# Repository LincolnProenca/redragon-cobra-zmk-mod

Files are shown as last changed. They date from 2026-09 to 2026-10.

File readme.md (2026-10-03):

# Custom ZMK Wireless Mouse: Redragon Cobra Mod 🖱️🐍

> **Hardware & Firmware Engineering Portfolio**

<p align="center">
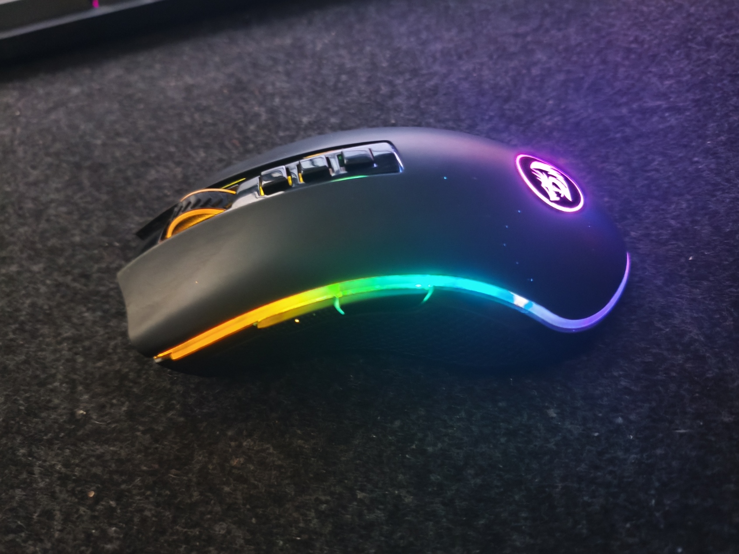
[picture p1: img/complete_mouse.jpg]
Finished Mouse with RGB
  
</p>

A comprehensive hardware and firmware project focused on creating a custom wireless mouse, built upon the Zephyr/ZMK ecosystem. A core idea behind this project was to create a versatile tool that seamlessly transitions between my work and home environments.

The project involved **designing a custom PCB**, specifically tailored to fit perfectly within the ergonomic shell of a **Redragon Cobra**. A key goal was to reuse as many components from the original mouse as possible—such as the switches and the wheel mechanism—transforming a traditional wired mouse into a premium, high-performance wireless tool.

Focused on energy efficiency, multiple productivity layers (Office/Gaming), and RGB Underglow lighting, the development overcame several electrical and logical challenges, especially in integrating high-consumption components (LEDs) with a _low-power_ sensor architecture.

## 📸 Project Gallery (Build Log)

<div align="center">
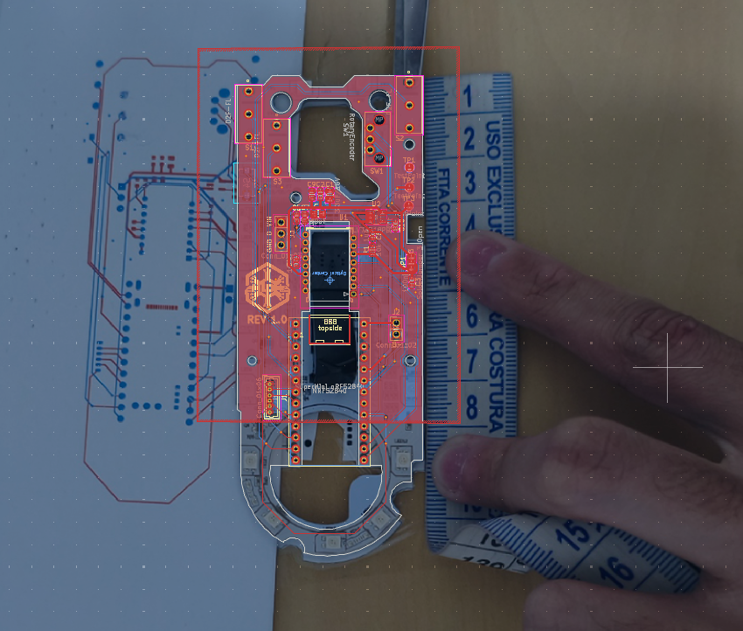
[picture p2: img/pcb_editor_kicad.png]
KiCad PCB Editor
  
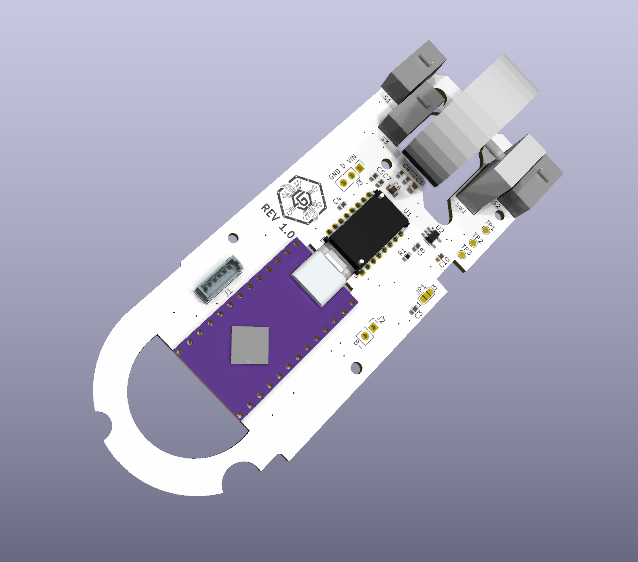
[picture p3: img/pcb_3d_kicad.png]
PCB 3D Render in KiCad
  
</div>
<br/>
<div align="center">
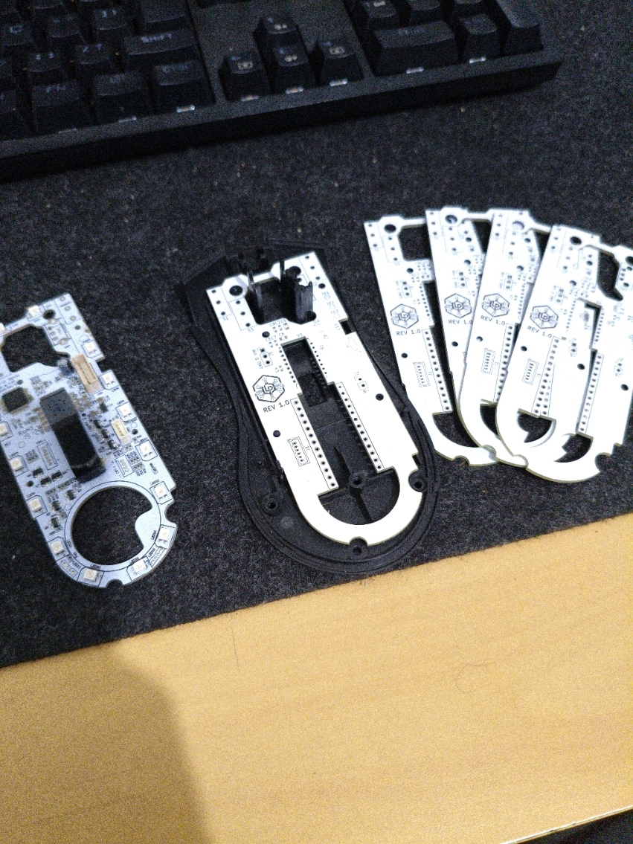
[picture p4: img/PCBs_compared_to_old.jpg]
Comparison with the Old PCB
  
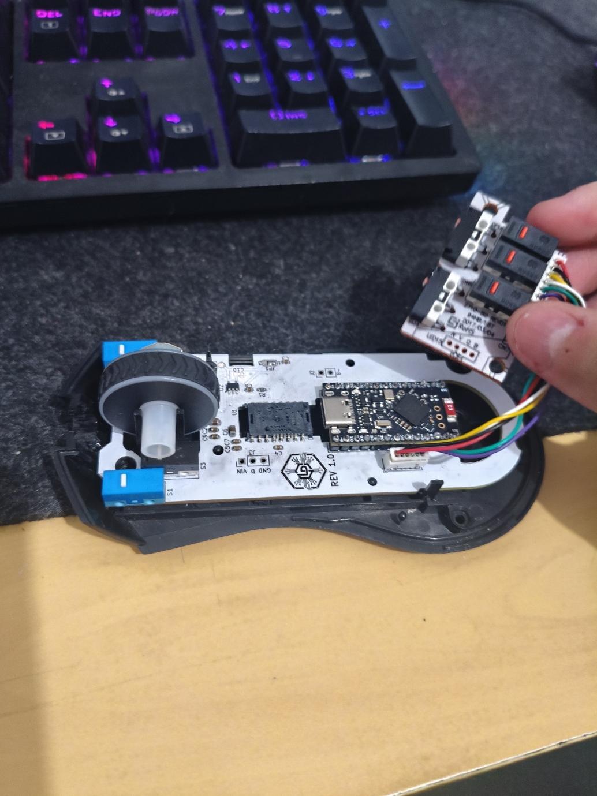
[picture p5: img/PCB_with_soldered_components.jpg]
Soldered PCB
  
</div>

## 🛠️ Hardware Specifications & Custom PCB

The hardware architecture was custom-developed to reuse the Redragon Cobra shell and its main functional components (like the original clicks and side switches). The integration includes:

- **Microcontroller:** SuperMini nRF52 (nice!nano alternative based on the nRF52840)
- **Optical Sensor:** PixArt PMW3610 (Since the original was a wired sensor, it was replaced with this Low-Power architecture ideal for wireless)
- **Scroll / Wheel:** TTC Gold 13mm Rotary Encoder (The original encoder was damaged and an exact replacement wasn't available, so it was swapped for this equivalent TTC Gold)
- **Lighting:** WS2812 LED Strip (9 LEDs for underglow)
- **Battery:** 1200mAh 3.7V LiPo (Model 503048, 5x30x48mm)
- **LED Power Control:** Two-stage power-gating circuit (level shifter): an **A19T P-channel MOSFET**(salvaged from a damaged SuperMini) switches the raw battery line (B+) to the LED strip VCC, and its gate is driven by an **SS8050 NPN transistor** (label Y1, salvaged from the original Redragon Cobra PCB) acting as a level shifter. The NPN base is driven by the MCU's `EXT_POWER` pin (GPIO 1.11) through a ~1.4k base resistor (also salvaged from the damaged SuperMini). This guarantees full enhancement and full cut-off of the MOSFET across the entire battery range (3.0V–4.2V).

## ✨ Features and Functionalities

The firmware was designed to act as a hybrid device (Mouse + Keyboard), allowing the execution of complex macros and direct shortcuts on the board.

### Layer System

- **Gaming Layer (Default):** Standard mouse commands (LCLK, RCLK, MCLK, MB4, MB5) with high-sensitivity scroll.
- **Office Layer:** Transforms the mouse into a productivity tool focused on **Simulink** environments. Features built-in macros (`Ctrl + .`, `C`, `E`, `N`, `T`, `E`, `R`) injected in 30ms for quick alignments, compiling, and block organization.
- **Utility Layer (Bluetooth Modifier):** Holding the "Top 3" button transforms the main clicks into a Bluetooth remote control (Force Slot 0, Force Slot 1, Format Memory).

### Physical Combos

- **TOP_1 + TOP_2:** Clean Soft Off (cuts `EXT_POWER` first, then enters deep sleep).
- **TOP_1 + TOP_3:** Toggle RGB On/Off.
- **TOP_2 + TOP_3:** Next RGB effect.
- **SIDE_1 + SIDE_2:** System Reset (Hardware sys_reset).
- **Bottom Button:** Directly triggers System Reset.

> Combos were deliberately moved off the main click buttons (LMB/RMB/MMB): any key position participating in a combo is held for up to `timeout-ms` on every press, which added perceptible latency to middle-click drags.

## ⚡ Engineering Notes & Hardware Solutions

During development, several electrical integration and mechanical design bottlenecks were resolved. If you intend to replicate this project, pay attention to the following design decisions and topology rules:

### 1. PCB Modeling and Component Alignment

Without schematics for the original Redragon Cobra PCB, the new board had to be modeled from scratch. The PCB outline and component placements were reverse-engineered using top-down photos of the original board and a physical ruler for scale.

### 2. 3D Modeling for Fitment Check

To ensure the SuperMini, LiPo battery, and all reused components would fit within the limited internal space of the original shell, a full 3D model of the assembly was created. This step was crucial to guarantee clearance for the new components without modifying the external plastics.

### 3. Wired to Wireless Conversion Challenges

Because the original Redragon Cobra was a wired mouse, several structural challenges were addressed:

- **Sensor Swap:** The original power-hungry wired sensor had to be replaced by the low-power PixArt PMW3610.
- **Charging Port Routing:** To utilize the original cable exit hole at the front of the mouse for charging, a custom-made male-to-female USB-C cable was fabricated. It routes power from the front of the mouse internally back to the SuperMini microcontroller.

### 4. Power Separation (Brownout Prevention)

The 9-LED WS2812 strip consumes up to ~180mA, which exceeds the chronic regulation capacity of the board's LDO, causing a _brownout_ (VCC drop to ~2.6V) if powered by the 3.3V pin.

- **Solution:** The board's VCC NPN Level Shifter + P-MOSFET)
  By default, WS2812 LEDs continuously drain quiescent current even when turned off (displaying black color) via software. To properly maximize battery life during sleep states, a hardware switch was implemented.

**The design constraint:** the LED strip is powered directly from the raw battery rail (B+), which swings between ~3.0V and 4.2V, while the MCU GPIOs only swing between 0V and 3.3V. Driving the gate of a P-channel MOSFET directly from a 3.3V GPIO is therefore unreliable: with a full battery (4.1V–4.2V), a logic-high GPIO produces a VGS of only about **-0.8V**, which is dangerously close to the low threshold voltage (VGS_th) of the A19T. A proper high-side switch needs the gate to be pulled all the way up to the source voltage (B+) to guarantee cut-off, and all the way down to GND to guarantee full enhancement — something a 3.3V GPIO cannot do on its own.

- **Solution (Hardware — two-stage level shifter):** The gate drive is handled by an **SS8050 NPN transistor** (label Y1, salvaged from the original Redragon Cobra PCB) wired as an open-collector level shifter:
  - **A19T P-MOSFET:** Source -> B+, Drain -> LED VCC, with a **10k pull-up resistor between Gate and Source** (keeps the MOSFET fully off by default).
  - **SS8050 NPN:** Collector -> A19T Gate, Emitter -> GND, Base -> `EXT_POWER` GPIO **1.11** through a **~1.4k base resistor** (salvaged from a damaged SuperMini).
- **How it works:** when `EXT_POWER` is low, the NPN is cut off and the 10k resistor pulls the gate up to B+ (VGS = 0V), fully turning the MOSFET off regardless of battery voltage. When `EXT_POWER` goes high (3.3V), the NPN saturates and pulls the gate to GND, producing VGS = -B+ (up to -4.2V), fully enhancing the MOSFET with minimal RDS(on). Both states are now referenced to the correct rails, so the circuit switches cleanly across the whole battery range with no leakage and no heating.

### 6. Boot Noise (LEDs flashing electronic junk)

When powering up the board, the nRF52 has floating pins that injected noise into the WS2812 strip's data channel.

- **Solution (`.overlay`):** Insertion of the `bias-pull-down;` property on the `pinctrl` MOSI pin to anchor the signal at 0V during boot, coupled with the initialization delay `init-delay-ms = <350>;` to wait for the strip's capacitors.

### 7. Physical Surface Conditioning

**Known Limitation:** The PixArt PMW3610 has extremely weak optical emission to save battery. It **does not work properly on wool or felt mousepads**, as the three-dimensional fibers blur the lens. It requires the use of traditional microfiber (cloth/fabric) mousepads or rigid surfaces.

### 8. PCB Rev1 Limitations & Rev2 Updates

**Known Limitation (Rev1):** Revision 1 (rev1) of the custom PCB does not natively route the Battery (B+) directly to the LED's VCC, nor does it include footprints for the power-gating circuit. These modifications (A19T P-MOSFET, SS8050 NPN, and resistors) had to be manually bodged (hardwired) onto the physical board.

**Rev2 Architecture Overhaul:** To eliminate the bulky discrete transistor assembly, the **Revision 2 (rev2)** of the PCB replaces the entire BJT+MOSFET circuit with a single **TPS22917DBV Load Switch** (SOT-23-6). 

- **How it works:** The raw battery line (B+) connects directly to `VIN`, and the MCU's `EXT_POWER` pin (GPIO 1.11) drives the `ON` pin directly. Since the TPS22917 features an internal smart level-shifter, it seamlessly interfaces a 3.3V GPIO with the fluctuating 3.0V–4.2V battery rail, ensuring a clean cut-off with sub-microampere leakage current.
- **Quick Discharge:** The `QOD` pin is tied directly to `VOUT` to leverage the internal 150Ω discharge resistor, instantly draining the LED strip's capacitors during sleep transitions.

> [!WARNING]
> **Rev2 Disclaimer:** While the Rev2 layout integrates these native traces, capacitors (1μ F input / 0.1μ F output), and the SOT-23-6 footprint, **this board revision has not been physically manufactured or tested yet**. If you plan to order it, please review the schematics and Gerber files carefully.

---

_Status: v1.0 (Full logical functionality validated in Hardware)._

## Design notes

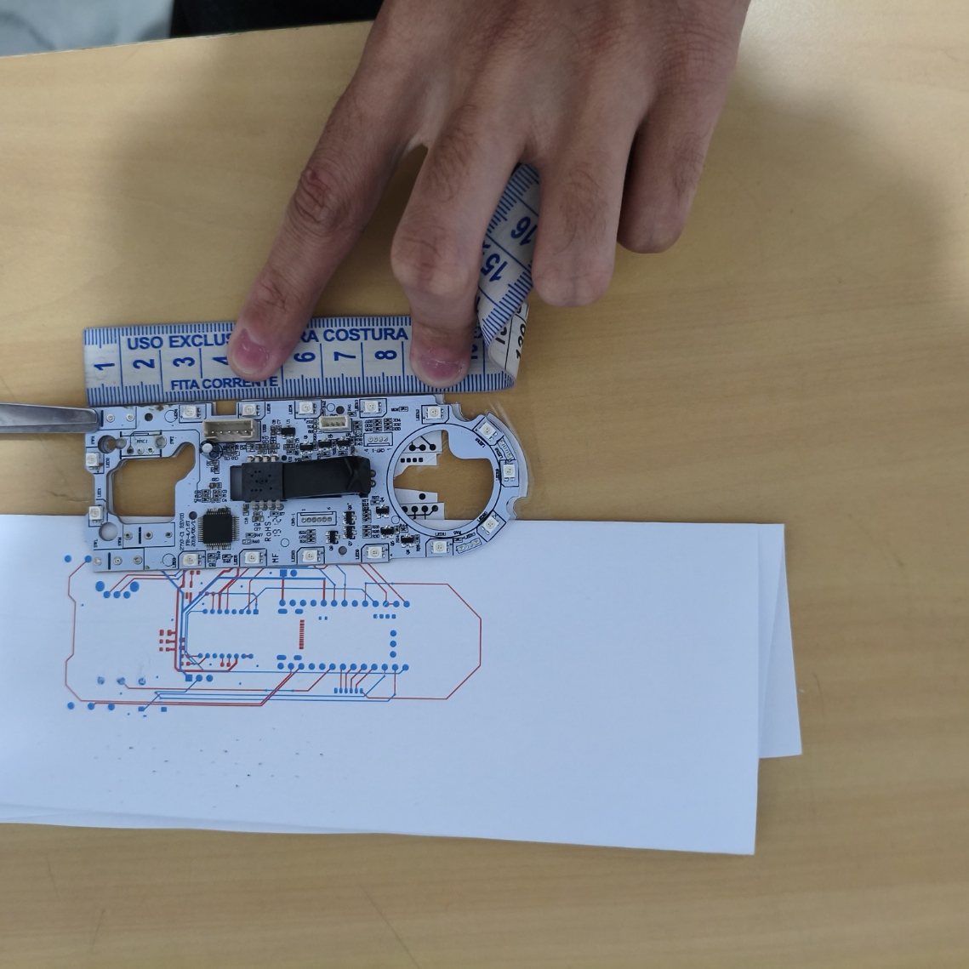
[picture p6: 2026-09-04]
PCB/Rev2/MVIMG_20260429_201309.jpg

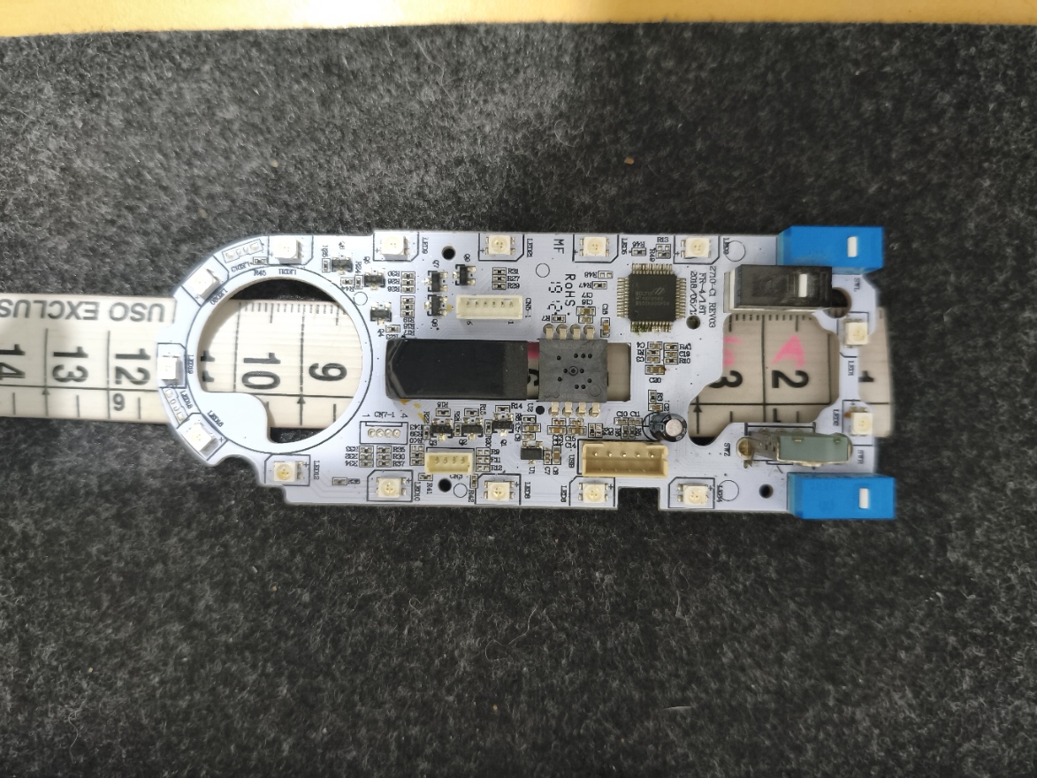
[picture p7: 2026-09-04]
PCB/Rev2/MVIMG_20260410_211105.jpg

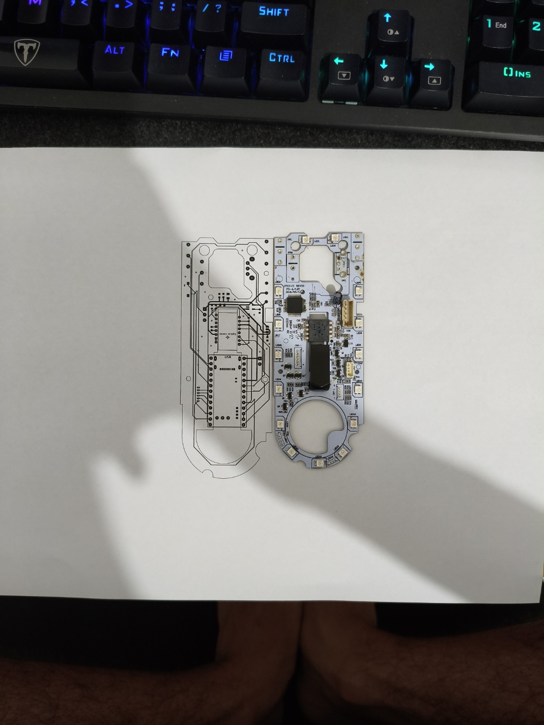
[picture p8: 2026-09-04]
PCB/Rev2/MVIMG_20260423_221846.jpg

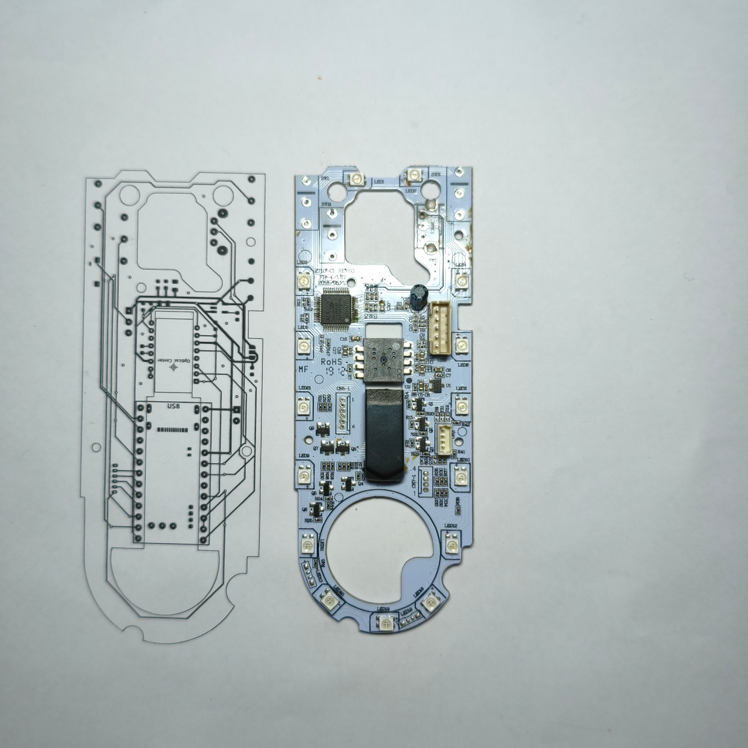
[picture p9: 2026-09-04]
PCB/Rev2/reference3.png

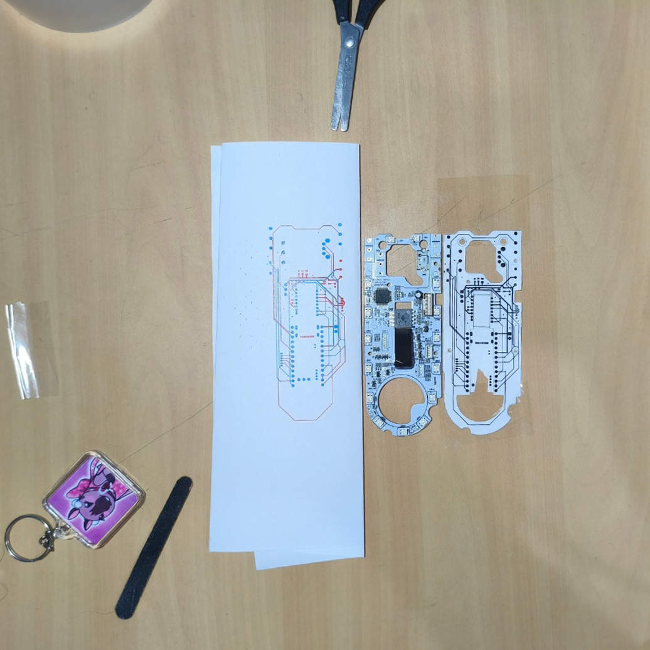
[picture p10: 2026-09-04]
PCB/Rev2/reference4.png

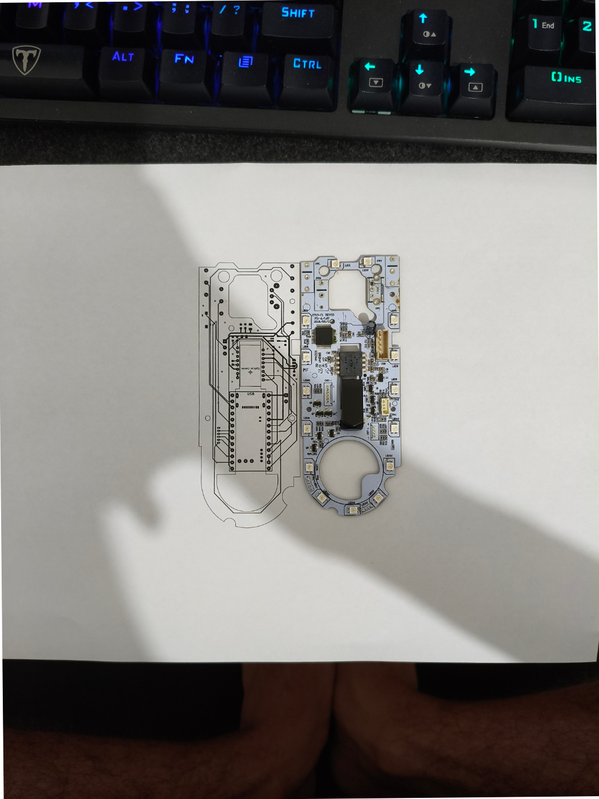
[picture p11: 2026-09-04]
PCB/Rev2/reference2.png

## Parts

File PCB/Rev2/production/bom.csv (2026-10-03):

Designator | Footprint | Quantity | Value | LCSC Part #
C1 | 0805 | 1 | 3.3uF/16V | C7393948
C10 | 0603 | 1 | 22nF | C21122
C11 | 0603 | 1 | 1uF
C12, C2, C3, C4 | 0603 | 4 | 100nF | C14663
C5, C7 | 0603 | 2 | 10nF | C57112
C6 | 0805 | 1 | 10uF | C15850
C8, C9 | 0603 | 2 | 1uF | C15849
J1 | Molex_PicoBlade_53047-0610_1x06_P1.25mm_Vertical | 1 | Conn_01x06
J2 | PinHeader_1x02_P2.54mm_Vertical | 1 | Conn_01x02
J3 | PinHeader_1x03_P2.54mm_Vertical | 1 | Conn_01x03
R1 | 0603 | 1 | 10k | C25804
S1, S2, S3 | SW_D2F-FL | 3 | D2F-FL
S4 | PTS636SKG25JSMTRLFS | 1 | PTS636SKG25JSMTR_LFS
SW1 | Rotary_Encoder | 1 | RotaryEncoder
U1 | PMW3610DM-SUDU 16Pin | 1 | PMW3610 | C42442560
U2 | SOT-23-5_HandSoldering | 1 | TLV74318PDBVR | C485152
U4 | SOT-23-6 | 1 | TPS22917DBV

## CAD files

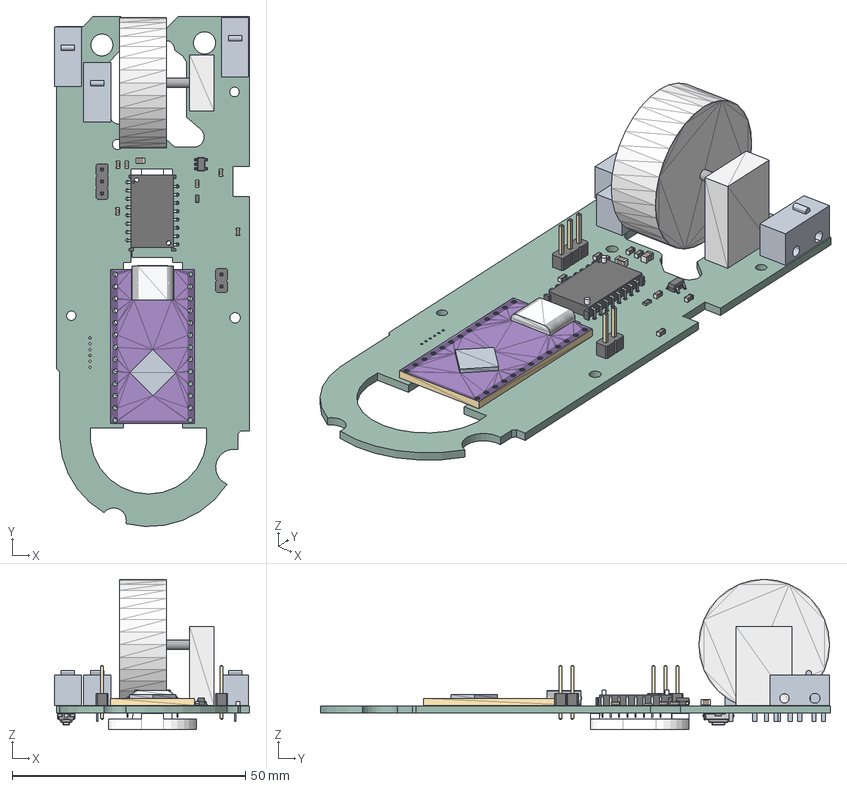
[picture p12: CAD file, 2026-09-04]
PCB/CustomPCB/.step
41.9 x 109.3 x 32.2 mm
C_0603_1608Metric x 8
C_0805_2012Metric x 2
PinHeader_1x02_P2.54mm_Vertical
encoder
SOT-23-5
PinHeader_1x03_P2.54mm_Vertical
Lead x 8
Lead(Mirror) x 8
Lens
D2F_ACTUATOR x 3
D2F_BASE x 3
R_0603_1608Metric
product0
product1
PTS636SKG25JSMTRLFS_PART1
PTS636SKG25JSMTRLFS_PART2
PTS636SKG25JSMTRLFS_PART3
PTS636SKG25JSMTRLFS_PART4
PTS636SKG25JSMTRLFS_PART5
PTS636SKG25JSMTRLFS_PART6
PTS636SKG25JSMTRLFS_PART7
CustomPCB_PCB

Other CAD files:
PCB/Rev2/.stl
PCB/CustomPCB/.stl
PCB/Rev1/.stl

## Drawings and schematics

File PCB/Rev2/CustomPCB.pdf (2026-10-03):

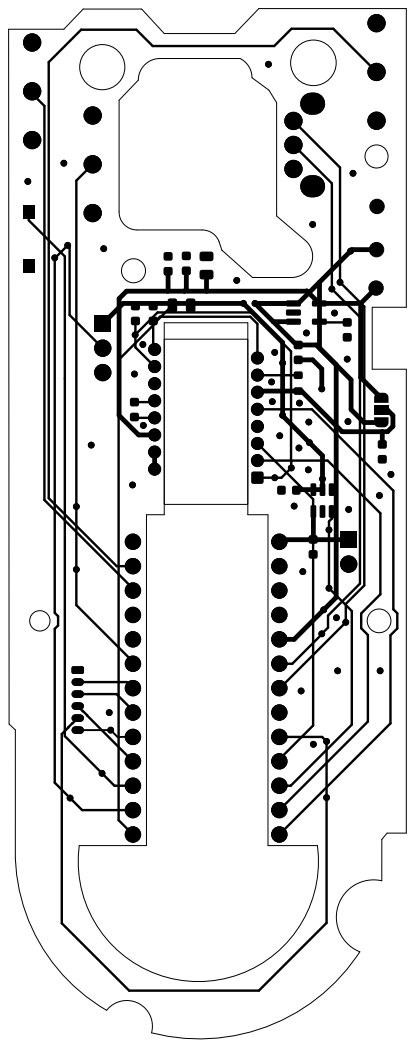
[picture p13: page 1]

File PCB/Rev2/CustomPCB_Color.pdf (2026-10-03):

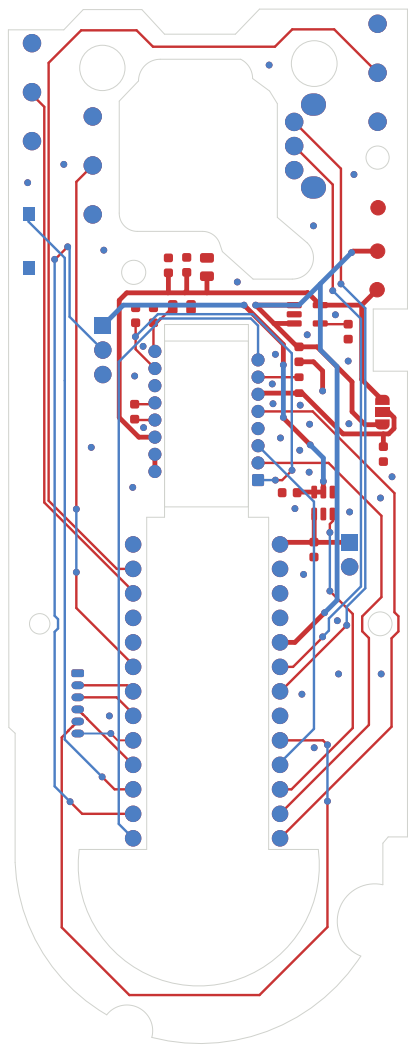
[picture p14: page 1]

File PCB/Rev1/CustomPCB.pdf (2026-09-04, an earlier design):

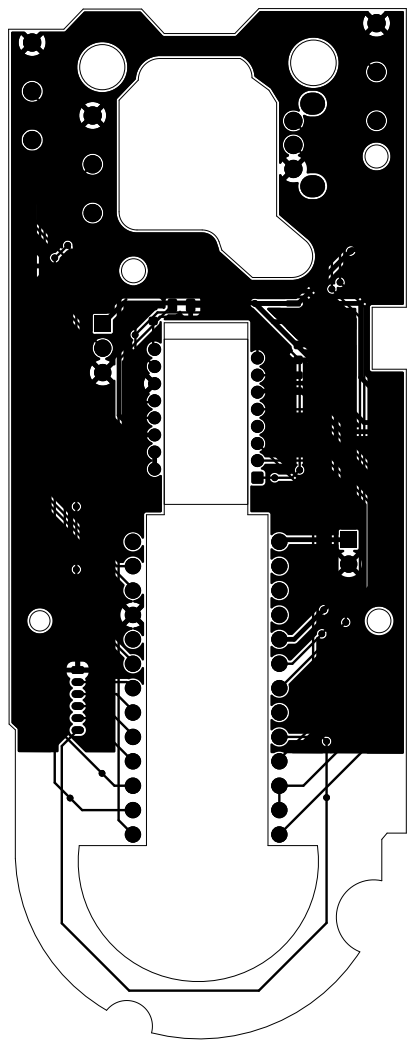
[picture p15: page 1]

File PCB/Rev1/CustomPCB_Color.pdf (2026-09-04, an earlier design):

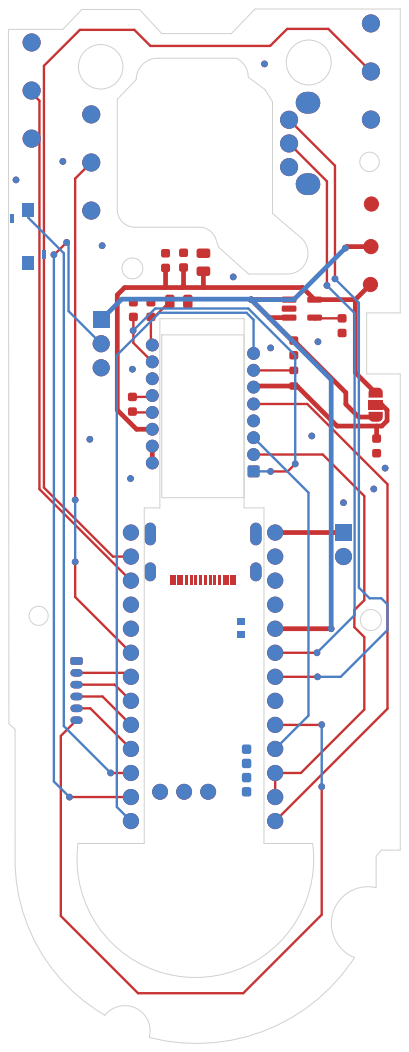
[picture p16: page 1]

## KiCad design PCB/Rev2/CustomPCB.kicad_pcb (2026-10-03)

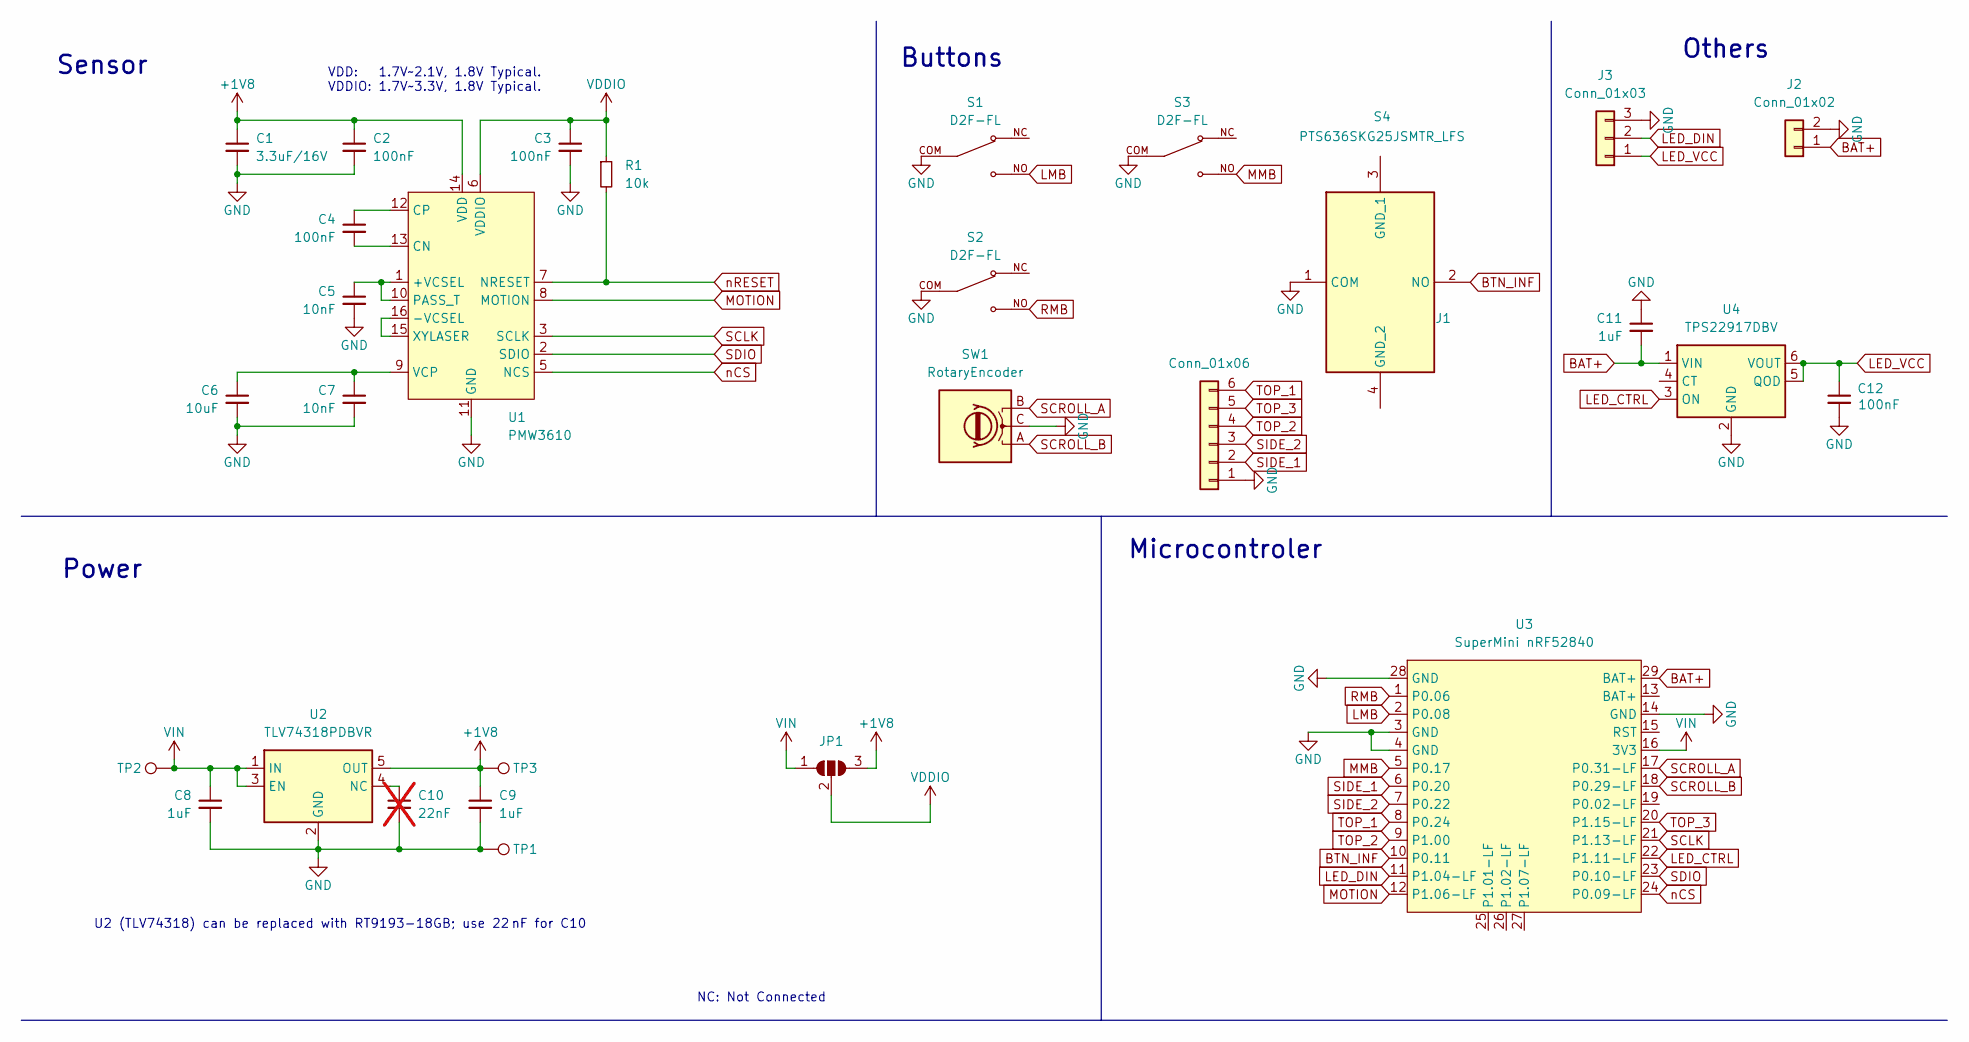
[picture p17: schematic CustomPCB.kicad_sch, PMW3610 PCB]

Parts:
C1: 3.3uF/16V; C_0805_2012Metric; MFR. Part # TCC0805X7R335K250FT; JLCPCB Part # C7393948
C2, C3, C4, C12: 100nF; C_0603_1608Metric; MFR. Part # CC0603KRX7R9BB104; JLCPCB Part # C14663
C5, C7: 10nF; C_0603_1608Metric; MFR. Part # 0603B103K500NT; JLCPCB Part # C57112
C6: 10uF; C_0805_2012Metric; MFR. Part # CL21A106KAYNNNE; JLCPCB Part # C15850
C8, C9: 1uF; C_0603_1608Metric; MFR. Part # CL10A105KB8NNNC; JLCPCB Part # C15849
C10: 22nF; C_0603_1608Metric; MFR. Part # CL10B223KB8NNNC; JLCPCB Part # C21122; not fitted
C11: 1uF; C_0603_1608Metric
J1: Conn_01x06; Molex_PicoBlade_53047-0610_1x06_P1.25mm_Vertical
J2: Conn_01x02; PinHeader_1x02_P2.54mm_Vertical
J3: Conn_01x03; PinHeader_1x03_P2.54mm_Vertical
JP1: SolderJumper_3_Open; SolderJumper-3_P1.3mm_Open_RoundedPad1.0x1.5mm_NumberLabels
R1: 10k; R_0603_1608Metric; MFR. Part # 0603WAF1002T5E; JLCPCB Part # C25804
S1, S2, S3: D2F-FL; SW_D2F-FL; PARTREV N/A
S4: PTS636SKG25JSMTR_LFS; PTS636SKG25JSMTRLFS; Mouser Part Number 611-PTS636SKG25JSMTR
SW1: RotaryEncoder; Rotary_Encoder
TP1, TP2, TP3: TestPoint; TestPoint_Pad_D1.5mm
U1: PMW3610; PMW3610DM-SUDU 16Pin; MFR. Part # PMW3610DM-SUDU; JLCPCB Part # C42442560
U2: TLV74318PDBVR; SOT-23-5_HandSoldering; MFR. Part # TLV74318PDBVR; JLCPCB Part # C485152
U3: SuperMini nRF52840; SuperMini NRF52840
U4: TPS22917DBV; SOT-23-6

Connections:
+1V8: C1.1, C2.1, C9.1, JP1.3 (B), TP3.1 (1_1), U1.14 (VDD), U2.5 (OUT)
BAT+: C11.2, J2.1, U3.29 (BAT+), U4.1 (VIN)
BTN_INF: S4.2 (NO), U3.10 (P0.11)
GND: C1.2, C2.2, C3.2, C5.2, C6.2, C7.2, C8.2, C9.2, C10.2, C11.1, C12.2, J1.1, J2.2, J3.3, S1.COM, S2.COM, S3.COM, S4.1 (COM), SW1.C, TP1.1 (1_1), U1.11 (GND), U2.2 (GND), U3.3 (GND), U3.4 (GND), U3.14 (GND), U3.28 (GND), U4.2 (GND)
LED_CTRL: U3.22 (P1.11-LF), U4.3 (ON)
LED_DIN: J3.2, U3.11 (P1.04-LF)
LED_VCC: C12.1, J3.1, U4.5 (QOD), U4.6 (VOUT)
LMB: S1.NO, U3.2 (P0.08)
MMB: S3.NO, U3.5 (P0.17)
MOTION: U1.8 (MOTION), U3.12 (P1.06-LF)
unnamed: C5.1, U1.1 (+VCSEL), U1.10 (PASS_T)
unnamed: U1.15 (XYLASER), U1.16 (-VCSEL)
unnamed: C4.2, U1.13 (CN)
unnamed: C4.1, U1.12 (CP)
unnamed: C6.1, C7.1, U1.9 (VCP)
unnamed: C10.1, U2.4 (NC)
RMB: S2.NO, U3.1 (P0.06)
SCLK: U1.3 (SCLK), U3.21 (P1.13-LF)
SCROLL_A: SW1.B, U3.17 (P0.31-LF)
SCROLL_B: SW1.A, U3.18 (P0.29-LF)
SDIO: U1.2 (SDIO), U3.23 (P0.10-LF)
SIDE_1: J1.2, U3.6 (P0.20)
SIDE_2: J1.3, U3.7 (P0.22)
TOP_1: J1.6, U3.8 (P0.24)
TOP_2: J1.4, U3.9 (P1.00)
TOP_3: J1.5, U3.20 (P1.15-LF)
VDDIO: C3.1, JP1.2 (C), R1.1, U1.6 (VDDIO)
VIN: C8.1, JP1.1 (A), TP2.1 (1_1), U2.1 (IN), U2.3 (EN), U3.16 (3V3)
nCS: U1.5 (NCS), U3.24 (P0.09-LF)
nRESET: R1.2, U1.7 (NRESET)

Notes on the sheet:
Others
Microcontroler
U2 (TLV74318) can be replaced with RT9193-18GB; use 22 nF for C10
Sensor
Power
NC: Not Connected
Buttons
VDD: 1.7V~2.1V, 1.8V Typical. VDDIO: 1.7V~3.3V, 1.8V Typical.

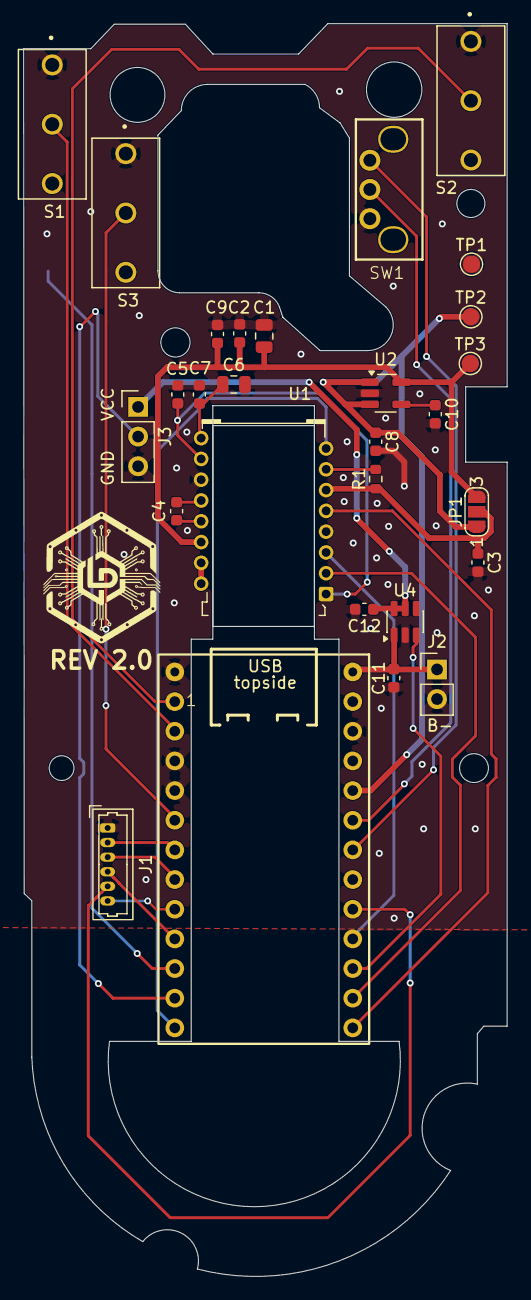
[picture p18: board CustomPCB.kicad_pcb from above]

Board: 2 copper layers, 41.4 x 107.3 mm, 30 parts (1 on the bottom side), 30 nets.

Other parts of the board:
REV 2.0: LOGO; logo

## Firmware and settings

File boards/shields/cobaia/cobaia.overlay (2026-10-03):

#include <zephyr/dt-bindings/input/input-event-codes.h>
#include <zephyr/dt-bindings/led/led.h>
#include <dt-bindings/zmk/matrix_transform.h>
#include <input/processors.dtsi>

/ {
    chosen {
        zmk,kscan = &kscan0;
        zmk,underglow = &led_strip;
        zmk,pointing = &pmw3610;
    };

    /*
     * LED power gating: two-stage level shifter.
     * - A19T P-MOSFET switches B+ to the LED strip VCC (source=B+, drain=LED VCC,
     *   10k pull-up between gate and source keeps it off by default).
     * - The gate is driven by an SS8050 NPN (open-collector level shifter):
     *   collector=gate, emitter=GND, base=GPIO 1.11 via ~1.4k.
     * - GPIO high (3.3V) saturates the NPN, pulling the gate to GND (VGS=-B+,
     *   full enhancement). GPIO low releases the gate to B+ via the 10k pull-up
     *   (VGS=0, full cut-off at any battery voltage).
     */
    EXT_POWER: EXT_POWER {
        compatible = "zmk,ext-power-generic";
        control-gpios = <&gpio0 13 GPIO_ACTIVE_HIGH>, <&gpio1 11 GPIO_ACTIVE_HIGH>;
        init-delay-ms = <350>;
    };

    kscan0: kscan_0 {
        compatible = "zmk,kscan-gpio-direct";
        wakeup-source;
        input-gpios
            = <&gpio0  8 (GPIO_ACTIVE_LOW | GPIO_PULL_UP)>   /* LMB */
            , <&gpio0  6 (GPIO_ACTIVE_LOW | GPIO_PULL_UP)>   /* RMB */
            , <&gpio0 17 (GPIO_ACTIVE_LOW | GPIO_PULL_UP)>   /* MMB */
            , <&gpio0 20 (GPIO_ACTIVE_LOW | GPIO_PULL_UP)>   /* SIDE_1 */
            , <&gpio0 22 (GPIO_ACTIVE_LOW | GPIO_PULL_UP)>   /* SIDE_2 */
            , <&gpio0 24 (GPIO_ACTIVE_LOW | GPIO_PULL_UP)>   /* TOP_1 */
            , <&gpio1  0 (GPIO_ACTIVE_LOW | GPIO_PULL_UP)>   /* TOP_2 */
            , <&gpio1 15 (GPIO_ACTIVE_LOW | GPIO_PULL_UP)>   /* TOP_3 */
            , <&gpio0 11 (GPIO_ACTIVE_LOW | GPIO_PULL_UP)>   /* BTN_INF */
            ;
    };

    left_encoder: encoder_left {
        compatible = "alps,ec11";
        a-gpios = <&gpio0 31 (GPIO_ACTIVE_LOW | GPIO_PULL_UP)>; /* SCROLL_A */
        b-gpios = <&gpio0 29 (GPIO_ACTIVE_LOW | GPIO_PULL_UP)>; /* SCROLL_B */
        steps = <24>;
        status = "okay";
    };

    sensors {
        compatible = "zmk,keymap-sensors";
        sensors = <&left_encoder>;
        triggers-per-rotation = <24>;
    };

    pmw3610_listener {
        compatible = "zmk,input-listener";
        device = <&pmw3610>;

        /* If Layer 1 is active, multiply the speed by 4/5 (1000 -> 800 DPI) */
        layer_slow {
            layers = <1>;
            input-processors = <&zip_xy_scaler 4 5>;
        };

        /* If Layer 2 is active, multiply the speed by 6/5 (1000 -> 1200 DPI) */
        layer_fast {
            layers = <2>;
            input-processors = <&zip_xy_scaler 6 5>;
        };
    };
};

&pinctrl {
    spi1_default: spi1_default {
        group1 {
            psels = <NRF_PSEL(SPIM_SCK, 1, 13)>,         /* SCLK */
                    <NRF_PSEL(SPIM_MOSI, 0, 10)>,        /* SDIO (TX) */
                    <NRF_PSEL(SPIM_MISO, 0, 10)>;        /* SDIO (RX) */
        };
    };

    spi1_sleep: spi1_sleep {
        group1 {
            psels = <NRF_PSEL(SPIM_SCK, 1, 13)>,
                    <NRF_PSEL(SPIM_MOSI, 0, 10)>,
                    <NRF_PSEL(SPIM_MISO, 0, 10)>;
            low-power-enable;
        };
    };
    
    spi3_default: spi3_default {
        group1 {
            psels = <NRF_PSEL(SPIM_MOSI, 1, 4)>;         /* LED_DIN */
            bias-pull-down;
        };
    };

    spi3_sleep: spi3_sleep {
        group1 {
            psels = <NRF_PSEL(SPIM_MOSI, 1, 4)>;
            low-power-enable;
        };
    };
};

&spi1 {
    status = "okay";
    compatible = "nordic,nrf-spim";
    pinctrl-0 = <&spi1_default>;
    pinctrl-1 = <&spi1_sleep>;
    pinctrl-names = "default", "sleep";
    cs-gpios = <&gpio0 9 GPIO_ACTIVE_LOW>;               

    pmw3610: pmw3610@0 {
        status = "okay";
        compatible = "pixart,pmw3610-alt";
        reg = <0>;
        spi-max-frequency = <2000000>;
        irq-gpios = <&gpio1 6 (GPIO_ACTIVE_LOW | GPIO_PULL_UP)>; 
        
        /* INPUT SUBSYSTEM UPDATE */
        evt-type = <INPUT_EV_REL>;
        x-input-code = <INPUT_REL_X>;
        y-input-code = <INPUT_REL_Y>;
        
        /* BASE HARDWARE CPI DEFINITION */
        cpi = <1000>;
        
        /* invert-y; */
        invert-x;
        swap-xy;
    };
};

&spi3 {
    status = "okay";
    compatible = "nordic,nrf-spim";
    pinctrl-0 = <&spi3_default>;
    pinctrl-1 = <&spi3_sleep>;
    pinctrl-names = "default", "sleep";
    
    led_strip: ws2812@0 {
        compatible = "worldsemi,ws2812-spi";
        reg = <0>;
        spi-max-frequency = <4000000>;
        chain-length = <9>;
        spi-one-frame = <0x70>;
        spi-zero-frame = <0x40>;
        color-mapping = <2 1 3>;
    };
};

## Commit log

2026-07-20 remove ext-power
2026-07-20 led fixes
2026-07-27 Enable swap-xy in cobaia overlaY
    [cobaia.overlay]
2026-07-27 Swap invert-x and invert-y configuration
    [cobaia.overlay]
2026-07-27 Update encoder GPIO settings and steps configuration
2026-07-30 Update left encoder GPIO settings to active high and remove tap-ms from scroll encoder behavior
2026-07-30 Refactor scroll encoder behavior to include tap-ms configuration
2026-07-30 Update scroll encoder bindings to use MOVE_Y for vertical scrolling
2026-07-30 Remove tap-ms configuration from scroll encoder behavior
2026-07-30 Update scroll encoder configuration to correct sensor bindings and tap-ms value
2026-07-31 Fix scroll encoder behavior to use compatible sensor-rotate-var
2026-07-31 Remove tap-ms configuration from scroll encoder and update gaming layer bindings
2026-07-31 add resolution property and flip scroll behavior
    [cobaia.overlay]
2026-07-31 Update left encoder resolution from 2 to 4
2026-07-31 Update left encoder resolution from 8 to 16
2026-07-31 Fix encoder GPIO configuration and reset resolution to 2
    [cobaia.overlay]
2026-07-31 Reduce tap duration for scroll encoder from 40ms to 20ms
2026-07-31 revert scroll encoder sensor bindings and add debounce period
    [cobaia.overlay]
2026-08-30 update LED strip configuration: change chain length to 9 and modify color mapping
2026-08-30 update ext-power initialization delay to 300 ms
2026-09-04 enable battery reporting and deep sleep features; update tap dance behavior to include soft off
2026-09-04 add switch debounce configuration and update tap dance timing for bootloader activation
2026-09-04 Add initial files for CustomPCB project and update configuration
    - Added CustomPCB.zip and multiple backup zip files for version control.
    - Created BOM (bill of materials) and designators CSV files for component management.
    - Generated netlist and positions CSV files for PCB layout.
    - Included reference images for design documentation.
    - Updated symbol library table for component references.
    - Disabled SPI3 in the Cobaia overlay for power management.
    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
    [.step, .stl, CustomPCB-.kicad_sch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]
2026-09-05 revert led and add bt_clr
    [cobaia.overlay]
2026-09-09 fix battery report overlay
    [cobaia.overlay]
2026-09-12 change battery report, add visual feedback on macro change, config led mosfet and fix layers conflict
    [cobaia.overlay]
2026-09-12 enable underglow ext power
2026-09-12 try another pin
2026-09-18 Update documentation and add Rev2 PCB
    [.step, .stl, CustomPCB-.kicad_sch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]
2026-10-03 added new mosfet, change 1.11 to active low
2026-10-03 Update Rev2 and documentation
    [CustomPCB.kicad_pcb, CustomPCB.kicad_sch, bom.csv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]

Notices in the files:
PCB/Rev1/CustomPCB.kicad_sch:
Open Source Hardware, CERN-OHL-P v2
